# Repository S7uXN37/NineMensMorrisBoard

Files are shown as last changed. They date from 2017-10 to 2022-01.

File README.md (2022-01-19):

# Nine Men's Morris

An intelligent board for Nine Men's Morris, using MiniMax and Deep Q Networks controlling a physical board via a Raspberry Pi

## Concept

Our algorithm was created based on the popular and relatively easy to implement "MiniMax" algorithm ([Wikipedia](https://en.wikipedia.org/wiki/Minimax)).

The algorithm works by recursively building a tree of possible future moves with a specified depth (we found that 3 works well; meaning we will look at the next 3 possible moves).
The states the game could be in after 3 moves are then assigned a value estimating good that state is for the player:

- Number of pieces; each piece the player has gives 3 points
- Number of possible moves; each possible move gives 0.1 points
- Number of mills; each mill gives 1 point

That value is calculated for both players and the state is assigned the difference, meaning how much better the player is doing than his opponent.
The algorithm then collapses the tree by assuming that both players play optimally, always trying to maximize the value of the board for them.
By the end, the algorithm then chosses the move with which the best board value can be guaranteed.

## Reasoning Behind Heuristics

Number of pieces:
- This is important to include as the main way to win in Nine Mens Morris is to bring your opponent down to 2 pieces so we want our AI to do whatever is possible to avoid losing. Furthermore, having more pieces gives more opprotunities to make mills.

Number of possible moves:
- When the number of possible moves goes down it is more likely that we could reach a point where we get trapped which would cause the AI to lose. Having a lower number of possible moves could also be correlated to having less pieces which we also want to avoid. Because of these reasons we want to keep the number of possible moves high.

Number of mills:
- The most common way to win is by taking away all but 2 of the opponents pieces and to do that we need mills. It's important that our AI chooses moves that causes them to get mills so it actually wins instead of being at a stalemate just trying to survive.

## Possible Additional Heuristics
- Number of intersections held. Intersections are very beneficial as they give you the most opprotunities to move either blocking a mill from your opponent or making one of your own
- Number of 2 in a row pieces: Before you create a mill often you start with 2 pieces in a row. As we want our AI to win it'd be a good idea to encourage it to make 2 in a row so it can make mills from there.

## Results:

**The Algorithm** can be run by executing:
``` shell
python test_human.py
```
To work properly, the GUI has to be enabled in the file `morris.py` using
``` python
GUI = True
```
To let the AI play first, you can skip the players first move in `test_human.py` using
``` python
skip_player = True
```
but make sure it is reset to `False` after the first move.

**Benchmarks** can be performed by running:
``` shell
python test_ai.py
```
The algorithm will compete against a randomly playing opponent.
To save information about time taken to compute moves, logging has to be enabled in `ai.py` using
``` python
LOG = True
```
The logging ooutput will be saved to a file called `log.csv`

The depth the algorithm examines can be changed in the file `ai.py` by changing the line
``` python
depth = 3
```
to use a customized value.

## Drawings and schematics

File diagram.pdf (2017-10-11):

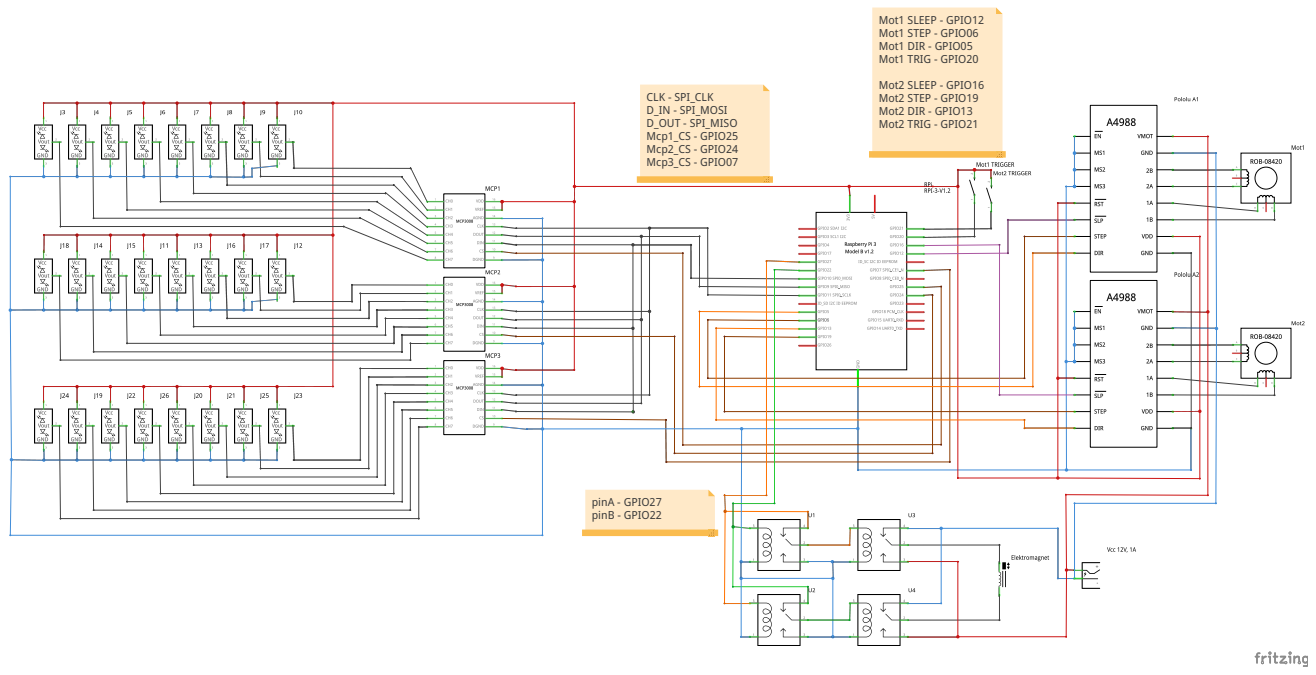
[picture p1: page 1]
pinA - GPIO27 pinB - GPIO22; Mot1 SLEEP - GPIO12 Mot1 STEP - GPIO06 Mot1 DIR - GPIO05 Mot1 TRIG - GPIO20; Mot2 SLEEP - GPIO16 Mot2 STEP - GPIO19 Mot2 DIR - GPIO13 Mot2 TRIG - GPIO21; CLK - SPI_CLK D_IN - SPI_MOSI D_OUT - SPI_MISO Mcp1_CS - GPIO25 Mcp2_CS - GPIO24 Mcp3_CS - GPIO07

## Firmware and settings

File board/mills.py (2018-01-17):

#!/usr/bin/env python
import ai
import time
import safe_path_generator as SPG
try:
    import RPi.GPIO as GPIO
    import motors
    import input
    import magnet
    TEST_MODE = False
except ImportError:
    TEST_MODE = True
import sys
import pygame

pygame.mixer.init()

COLOR_AI = 1
COORDS = [(0,0), (0,3), (0,6),    (1,1), (1,3), (1,5),    (2,2), (2,3), (2,4),    (3,0), (3,1), (3,2),    (3,4), (3,5), (3,6),    (4,2), (4,3), (4,4),    (5,1), (5,3), (5,5),    (6,0), (6,3), (6,6)]
order_arr = [[8, 2, 0, 4, 6, 5, 1, 3, 7].index(x) for x in range(9)]  # which base field is accessed when (the first at time 8, the second at time 2)
COORDS.extend([(-0.22+(6.44/8*x), -0.64) for x in order_arr])  # BASE_AI from 24 - 32
COORDS.extend([(6.22-(6.44/8*x), 6.64) for x in order_arr])  # BASE_PLAYER from 33 - 41

shutdownPin = 11
ledPin = 3

old_board = [0] * 24
pieces_player = 9
pieces_taken = 0
pieces_ai = 9

# Returns the updated board index referring to a specific position in the base instead of the base in general
def resolve_base(_i, base_color):
    if _i != -1:  # no effect on normal fields
        return _i
    if base_color == COLOR_AI:
        return 24 + 9 - pieces_ai
    else:
        # list: where to put taken pieces first in player base (such that all pieces can be placed in the worst case)
        return 33 + [2, 4, 6, 5, 3, 1, 0][pieces_taken]
def resolve(_i, context_board, base_color):
    global pieces_player, pieces_ai
    if _i == -1:  # -1 corresponds to a position in the base
        return COORDS[resolve_base(_i, base_color)], base_color
    else:
        return COORDS[_i], context_board[_i]

def getShortSafePath(_board, start, target):
    if target == -1 or start == -1:
        raise RuntimeError('Position in base must be resolved first')
    start_pos = COORDS[start]
    target_pos = COORDS[target]
    safe_path = [start_pos]
    safe_path.extend(SPG.generate(start, target))  # list of tuples, first = start, last = target
    safe_path.append(target_pos)
    
    print('safe path from %i to %i is: %s' % (start, target, str(safe_path)))
    return safe_path

def reset():
    global pieces_player, pieces_ai
    # Resets all pieces to the base, clears any records of previous boards
    time.sleep(2)
    print('Resetting the board')
    _board = input.readBoard()
    for _i, val in _board:
        if val != 0:
            _pos, _ = resolve(_i, _board, COLOR_AI)
            _dest, _ = resolve(-1, _board, val)
            if val == COLOR_AI:
                pieces_ai += 1
            else:
                pieces_player += 1
            motors.goTo(_pos[0], _pos[1])
            magnet.turnOn(val)
            _path = getShortSafePath(board, start, _dest)
            for p in _path:
                motors.goTo(p[0], p[1])
            magnet.turnOff()
            time.sleep(0.5)

running = True
def shutdown(channel=0, full=True):
    if running:
        return
    print("Shutting down...")
    input.shutdown()
    motors.shutdown()
    magnet.shutdown()
    GPIO.output(ledPin, GPIO.LOW)
    if full:
        sys.exit(1)
    else:
        sys.exit(0)

def count(_board, _color):
    num = 0
    for val in _board:
        if val == _color:
            num += 1
    return num

# These methods play a sound, wait for it to finish and then wait 0.5s more
def play_sound(_path):
    print('playing sound: %s' % _path)
    pygame.mixer.music.load(_path)
    pygame.mixer.music.play()

if __name__ == "__main__" and not TEST_MODE:
    try:
        GPIO.setup(ledPin, GPIO.OUT)
        GPIO.output(ledPin, GPIO.HIGH)
        GPIO.setup(shutdownPin, GPIO.IN, pull_up_down=GPIO.PUD_DOWN)
        GPIO.add_event_detect(shutdownPin, GPIO.RISING, callback=shutdown)

        print('Resetting motors...')
        motors.reset()
        while True:
            running = False
            print('Checking board...')
            board = input.readBoard()
            should_move = False
            if old_board != board:
                # A move is over when a stone has been moved -> same number of pieces in phase 2/3
                # or when a stone has been placed -> number of player pieces increased by 1
                # If a mill has just been closed (new stone isInMill), after a COLOR_AI piece has been removed
                # If one color now only has two pieces left, the game is over -> clean board
                num_ai_old = count(old_board, COLOR_AI)
                num_ai = count(board, COLOR_AI)
                num_pl_old = count(old_board, -COLOR_AI)
                num_pl = count(board, -COLOR_AI)
                pl_move_dest = -1
                for i, v in enumerate(board):
                    if old_board[i] == 0 and v == -COLOR_AI:  # player piece added
                        pl_move_dest = i
                if num_ai < 3 and pieces_ai == 0:  # AI just lost
                    print('Suppose I\'ve lost :(')
                    play_sound('../sounds/clap.wav')
                    reset()
                    continue
                if ai.isInMill(board, pl_move_dest):  # If a mill was closed, the move ends when one num_ai decreases by 1
                    should_move = num_ai == num_ai_old-1
                    if should_move:
                        print('Found closed mill on field %i, AI piece removed' % pl_move_dest)
                else:  # otherwise, both players must have the same number of pieces as before
                    phase_one = pieces_player != 0 and pieces_ai != 0
                    should_move = ((not phase_one) and num_pl == num_pl_old and num_ai == num_ai_old) \
                                   or (phase_one and num_pl == num_pl_old+1 and num_ai == num_ai_old)
                    if should_move:
                        print('Found move to %i without any closed mills' % pl_move_dest)
            if should_move:
                running = True
                print('board: ' + str(board))
                play_sound('../sounds/ping.wav')
                print('calculating move... p_ai=%i p_pl=%i' % (pieces_ai, pieces_player))

                if pieces_player > 0:  # ASSUME player uses all pieces from their storage before playing normally
                    pieces_player -= 1

                old_board, moves = ai.calcMove(board, COLOR_AI, pieces_ai, pieces_player)
                for move in moves:
                    start = move[0]
                    dest = move[1]
                    print('move: ', move[0], 'to', move[1])

                    # resolve coords of start and dest & color of piece
                    c1, color = resolve(start, board, COLOR_AI)  # can only move pieces out of own base
                    c2, _ = resolve(dest, board, COLOR_AI)  # can only put pieces in opponents base

                    # move piece from start to dest
                    motors.goTo(c1[0], c1[1])
                    magnet.turnOn(color)
                    if start == -1 or count(board, COLOR_AI) <= 3 or dest == -1:
                        path = getShortSafePath(board, resolve_base(start, COLOR_AI), resolve_base(dest, -COLOR_AI))
                    else:
                        path = [c1, c2]
                    for pos in path:
                        motors.goTo(pos[0], pos[1])
                    magnet.turnOff()
                    if dest == -1:  # after piece has been moved to the player's base, we can update pieces_taken
                        pieces_taken += 1
                    time.sleep(0.5)
                motors.goTo(0, 0)
                motors.reset()

                if pieces_ai > 0:  # ASSUME AI uses all pieces from its storage before playing normally
                    pieces_ai -= 1

                #old_board = input.readBoard()
                print("board: " + str(old_board))
                if count(old_board, -COLOR_AI) < 3 and pieces_player == 0:  # AI just won
                    play_sound('../sounds/fanfare.wav')
                    reset()
                    continue
                running = False
            else:
                time.sleep(1)
    except KeyboardInterrupt:
        shutdown(full=False)

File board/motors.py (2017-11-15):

import RPi.GPIO as GPIO
import time
import threading
usleep = lambda x: time.sleep(x/1000.0/1000.0)

coordToSteps = 2000.0 / 6.0
RESET_POS = [-0.22, -0.64] # 6.6cm/grid -4cm/6.6=-0.6, -1.5cm/6.6=-0.22

# Mot1 on board, Mot2 below
dirPin = [29,33]
stepPin = [31,35]
sleepPin = [32,36]
triggerPin = [16,40]
triggerSet = [False, False]
delay = 1800.0

stop = False

def daemon():
    c = 0
    while not stop:
        time.sleep(0.01)
        if GPIO.input(triggerPin[0]) == 1:
            c += 1
        else:
            c = 0
        if c == 5:
            triggerSet[0] = True
def trigger1(channel):
    triggerSet[1]=True

def move(steps):
    for j in range(2):
        GPIO.output(dirPin[j], GPIO.HIGH if steps[j]<0 else GPIO.LOW)
        if not steps[j] == 0:
            GPIO.output(sleepPin[j], GPIO.HIGH)
        steps[j] = abs(steps[j])
    time.sleep(0.15)
    for i in range(max(steps[0], steps[1])):
        for j in range(2):
            if i>=steps[j]:
                continue
            GPIO.output(stepPin[j], GPIO.HIGH)
            usleep(1)
            GPIO.output(stepPin[j], GPIO.LOW)
        t = 400.0 #steps until full speed
        d_start = 4000.0 #start delay
        f_i = (d_start-delay)/(t*t) * (i-t)*(i-t) + delay #calc delay
        usleep(f_i if i < t else delay)
    time.sleep(0.1)
    for j in range(2):
        GPIO.output(sleepPin[j], GPIO.LOW)

GPIO.setmode(GPIO.BOARD)

# Initialize to LOW
for pin in [dirPin, stepPin, sleepPin]:
    GPIO.setup(pin, GPIO.OUT, initial=GPIO.LOW)
GPIO.setup(triggerPin[0], GPIO.IN, pull_up_down=GPIO.PUD_DOWN)
GPIO.setup(triggerPin[1], GPIO.IN, pull_up_down=GPIO.PUD_DOWN)
d = threading.Thread(name='Daemon', target=daemon)
d.setDaemon(True)
d.start() # Event detect doesn't work because of fluctuations
GPIO.add_event_detect(triggerPin[1], GPIO.RISING, callback=trigger1)

posx = 0
posy = 0

def goTo(tx, ty):
    global posx, posy
    x = int((tx - posx) * coordToSteps)
    y = int((ty - posy) * coordToSteps)
    print("Moving from " + str((posx,posy)) + " to " + str((tx,ty)))
    move([x,y])
    posx = tx  # Must be in simple coordinate system!
    posy = ty

def reset():
    goTo(RESET_POS[0], RESET_POS[1])
    global posx, posy
    posx = RESET_POS[0]
    posy = RESET_POS[1]
    triggerSet[0] = (GPIO.input(triggerPin[0]) == 1)
    while not triggerSet[0]:
        xy = [-10, 0]
        move(xy)
    triggerSet[1] = (GPIO.input(triggerPin[1]) == 1)
    while not triggerSet[1]:
        xy = [0, -10]
        move(xy)

def shutdown():
    GPIO.output(sleepPin[0], GPIO.LOW)
    GPIO.output(sleepPin[1], GPIO.LOW)
    stop = True

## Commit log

2017-02-06 Finished AI, deleted Java Project
    [log.xlsx]
2017-04-11 Motor.py file, tests folder
2017-04-11 Fritzing sketch
    [fritzing_sketch.fzz]
2017-04-14 Updated sketch
    [fritzing_sketch.fzz]
2017-05-26 Updated diagram
    [fritzing_sketch.fzz]
2017-06-25 Began implementation of board code
    According to Diagram on GoogleDrive, 5 classes will control the board:
    - mills.py: GameController
    - ai.py: AI
    - magnet.py: Magnet controller
    - input.py: Reading hall sensors
    - motors.py: Running motors
2017-06-28 Update
    Tests working with finished circuitry
2017-07-03 Minor improvements on code, started over with mills.py
2017-07-05 Changed motors.py (added goTo), added TODO's
2017-08-15 Minor polish, progress in mills.py
    Space indentation instead of tabs
    Fixed minor errors
    Implemented resolve() in mills.py
    TODO:
    - Add coordinate look-up tables in mills.py
    - Return moves instead of board in ai.py
    [ai.py, input.py, mills.py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]
2017-09-26 Successfully reading sensors and controlling motors
2017-10-01 Updated AI, prepared interface classes
    Incorporated move structure into AI:
    Created "change" class to hold new board and moves to get there, this way we only have to pass a simple list and can extract the end state along with ALL moves needed to get there.
    Interfaces:
    Deleted obsolete code, added placeholders to be filled in with code from tests using the not-yet-pushed code on the RPi tomorrow
2017-10-01 Magnet and Switch tests
2017-10-02 Bug fixes in AI
    Added deleted code from commit #205962e back into mills_old.py to get pygame running again
    Fixed test_ai.py and test_human.py to check code
    Bugs in AI:
    line 68: The final layer did not return moves, so recursion crashed due to a lack of returned values
    line 76: line 83 depends on board_after being a numpy array
    line 120-178: Due to copy-paste, the wrong places were checked to see if a mill had closed and wrong moves were submitted
    [ai.py, mills_old.py, test_human.py]
2017-10-02 Working prototype
    Can't yet move around existing pieces
2017-10-16 Search algorithm for shortest safe path
    TODO: function for known safe path
    [mills.py]
2017-10-18 Bug fixes in mills.py
2017-10-18 Fixes in mills.py
    Range for k in line 69 was wrong
    Removed stone to be moved from board -> no collision with itself
    Changed dist_to_line to dist_to_line_seg
    [mills.py]
2017-10-18 Minor changes
    TODO: distance_to_line_seg not working properly.
    Test case: p0=(1,1) s=(0,0) t=(6,6)
    [mills.py]
2017-10-19 Reworked getShortSafePath
    Because the robot moves diagonally until its first coordinate is correct and then laterally, our isUnblocked method does not reflect reality.
    The robot now follows the rectangular path; isUnblocked could be implemented later again with the correct path simulation.
    The base pieces will be placed evenly distributed on either side.
    For moving pieces out of the base that are "hidden" behind other base pieces and a field on the board, other pieces have to be moved out of the way first.
    - correct order in BASE_COORDS such that coordinates accessed first are always safe to move out of
    - implement into SPG
    IMPORTANT:
    - base fields should act like normal fields, using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
    [mills.py]
2017-10-20 Added base handling
    - player's base is treated with point-symmetry with respect to the middle of the board
    - player must remove stones in correct order
    - ai has specified order to move stones out of the base, that ensures the path to the SPG-node (3rd piece from either side) is always clear
    - SPG cannot receive -1 as an argument!
    [mills.py, safe_path_generator.py]
2017-10-20 Completed remaining TODO's
    - deleted testfile.py -> we know know that we have to use python3 in order for SPG to work
    - removed TODO in magnet.py -> worked with correct polarization
    [magnet.py]
2017-10-25 Update safe_path_generator.py
    Fixed connection into base
    [safe_path_generator.py]
2017-10-26 Added test script for CONNECTIONS
    Fixed a mistake in CONNECTIONS (node 29 being connected to itself)
    [safe_path_generator.py, spg_test.py]
2017-10-31 Histogram for sensor data, adjusted detection limits
2017-11-02 Arduino Serial via USB
2017-11-02 Fixed bug with SPG
    [mills.py]
2017-11-02 Added shutdown button
2017-11-03 Bug fixes
    Fixed magnet communication w/ python3
    Commented out shutdown function, added necessary setup() for later
    [magnet.py, mills.py, motors.py]
2017-11-05 Different changes
    SPG: mirrored coordinate system to comply with rest of program
    magnet: mirrored color
    Pin changes:
    Trigger upper - 13
    Shutdown button - 11
    LED - 3
2017-11-07 Working trigger0 using daemon thread
2017-11-09 Motors fixed
2017-11-12 Fixed taking enemy pieces, changed path to move directly in 2nd phase
    [mills.py]
2017-11-22 Began work on test to show path
    Minor fixes in mills.py, reworked for import on not RPi
    [mills.py, test_human.py]
2017-11-22 Fixed SPG problems
    Continued work on test_human (working okay w/o noticeable problems - putting pieces back into the base must be sorted out)
    Mills.py doesn't put pieces in own base because SPG resolve is not using COLOR_AI, but -COLOR_AI
    [safe_path_generator.py, test_human.py]
